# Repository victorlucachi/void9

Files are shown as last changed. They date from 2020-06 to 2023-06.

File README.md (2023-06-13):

# VOID9
*A 3x3 handwired macropad*

VOID9

The VOID9 is a 3d printed, handwired, 4x4 macropad running QMK Firmware on a Pro Micro controller.

I suggest printing the case using a 0.4 mm nozzle, supports are not needed for any of the parts.

You might want/need to use small dabs of hot glue to secure the switches in the plate depending on how well calibrated your printer is (if you're generous with it, it will add to the weight of the keyboard and it might change the feel of it).

Dont overtighten the screws as the threads might get stripped.

# WARNING

Comlumn pinout has been revised, if you have an older build of the macropad (built before October 2022, which was using pins D1, D0, D4) edit the info.json file in the firmware forks in order to reflect your wiring!

# Bill Of Materials

* 9 x diodes ([tme.eu](https://www.tme.eu/ro/en/details/1n4148-dio/tht-universal-diodes/diotec-semiconductor/1n4148/)/[aliexpress](https://www.aliexpress.com/item/32729204179.html))
* 9 x Cherry MX style mechanical switches
* 9 x keycaps of choice
* 1 x Pro Micro ([aliexpress](https://www.aliexpress.com/item/32902569443.html))
* 24 AWG (0.2 mm2) wire
* 4 x 8mm bumpons

### Redux
* 6 x M2x3x3.5 OD heat inserts ([aliexpress](https://www.aliexpress.com/item/4000585933306.html?spm=a2g0o.order_list.order_list_main.33.21ef1802vdSNrS))
* 4 x M2x10 Allen head screws ([aliexpress](https://www.aliexpress.com/item/32966941844.html?spm=a2g0o.order_detail.order_detail_item.9.722ff19cyjrixq))
* 2 x M2x6 Countersunk screws ([aliexpress](https://www.aliexpress.com/item/32968097507.html?spm=a2g0o.order_list.order_list_main.32.21ef1802vdSNrS))

### V1
* 4 x M3x10 Allen head bolts ([tme.eu](https://www.tme.eu/ro/en/details/m3x10_d912-a2/bolts/kraftberg/)/[aliexpress](https://www.aliexpress.com/item/32966941844.html))
* hotglue

# Community Mods

Contributions by @dlehman

Bottom - Angled - Short: Designed to be used with the middle ring (Middle - Angled: eg. if you want a contrasting color stripe). The short bottom + middle layer will be the same height as the regular bottom.

Bottom - Angled - Short - Teensy2: A version of the "Bottom - Angled - Short" model designed for a [Teensy 2.0 controller](https://www.pjrc.com/store/teensy.html) with a Mini (not "micro") USB port on it.

# Handwiring guide

I've also put together a pretty visual handwiring guide for the VOID9, that you can browse over [here](https://victorlucachi.ro/journal/void9-wiring-guide/).

|  	|  	|  	|
|---|---|---|

# Pin assignment

    ROW0    ROW1    ROW2
    F4      F5      F6

    COL0    COL1    COL2
    D1      D4      D0
    
    Encoder Pad A           Encoder Pad B
    B1                      F7
    B2                      B3

# QMK Vial Fork

A QMK Vial fork can be found [here](https://github.com/victorlucachi/vial-qmk/tree/dev_void/keyboards/handwired/void9).

Most features are disabled in order for the firmware to fit on the atmega32u4 present on the Pro Micro controllers, but if you want to tinker around with different features or if you're using a different MCU you can enable/disable them to suit your own needs by editing the rules.mk file in the vial keymap folder.

The web version of Vial is available at [vial.rocks](https://vial.rocks/); it runs in supported browsers (Chrome, Edge and Opera) without requiring an installation.

VOID9 Vial

# QMK Fork

A fork containing the QMK config files can be found [here](https://github.com/victorlucachi/qmk_firmware/tree/dev_void/keyboards/handwired/void9). Edit them to suit your own needs and build the firmware following the QMK docs.

If you plan on using the VIA configurator dont forget to download the json definitions file linked in this repository.



This work is licensed under a [Creative Commons Attribution-NonCommercial-ShareAlike 4.0 International License](https://creativecommons.org/licenses/by-nc-sa/4.0/).

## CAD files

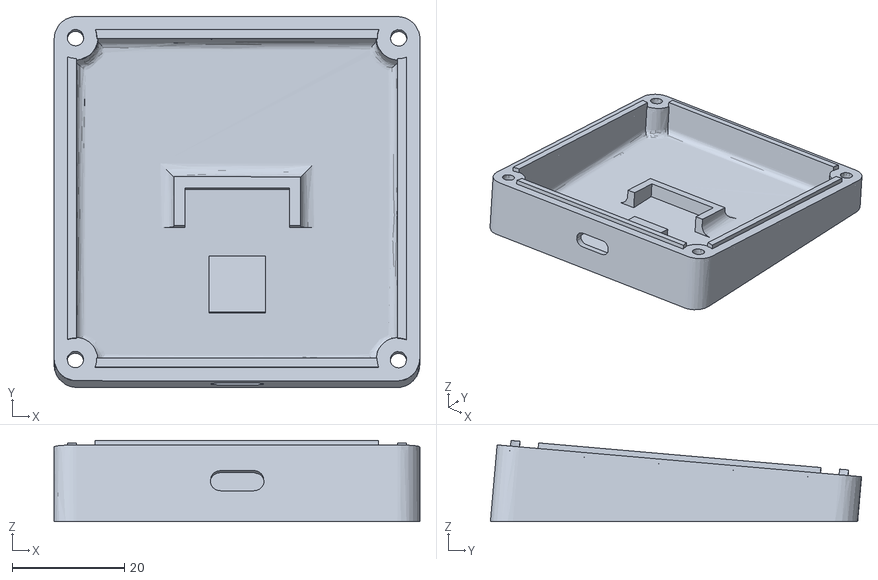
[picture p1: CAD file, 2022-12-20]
Community Mods/VOID9 - Bottom - Angled - Short.stl
65.2 x 66.1 x 14.4

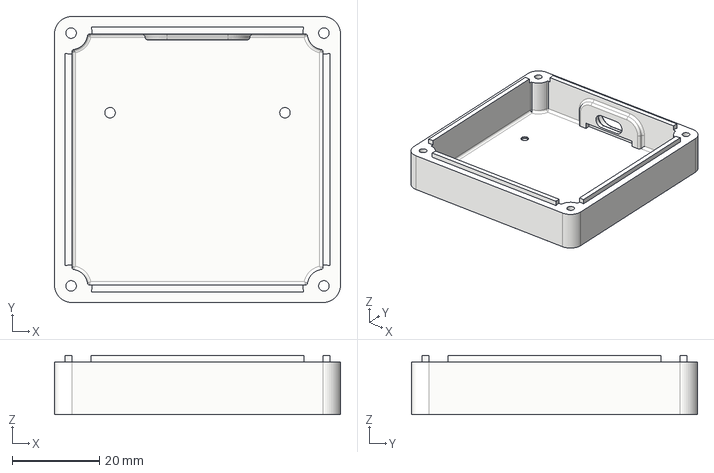
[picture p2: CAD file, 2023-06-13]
Redux/STEP/VOID9 Redux - Bottom - Flat.step
65.4 x 65.4 x 13.5 mm

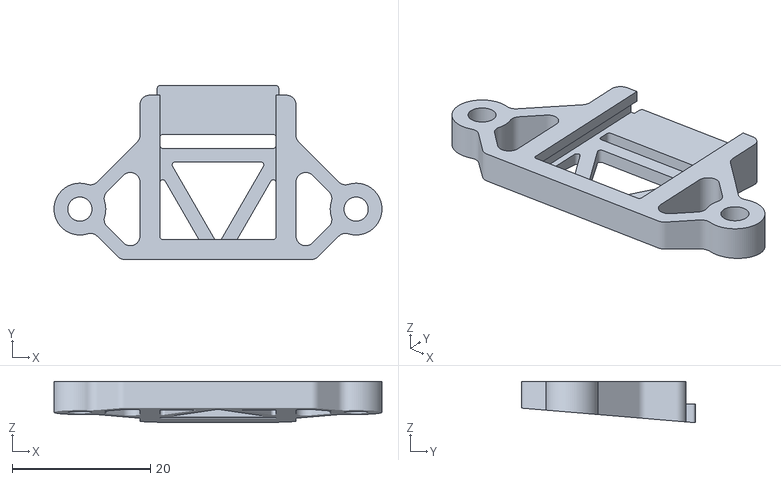
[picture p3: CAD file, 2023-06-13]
Redux/STL/Controller/21.5x18mm - Seeed Xiao - Angled.stl
47.5 x 25.2 x 6.00

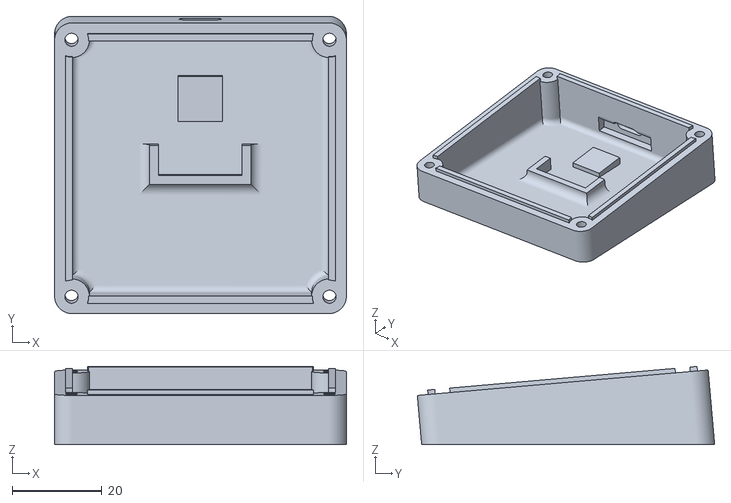
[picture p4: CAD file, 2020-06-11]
v1/STL/VOID9 - Bottom - Angled.stl
65.2 x 66.4 x 17.4

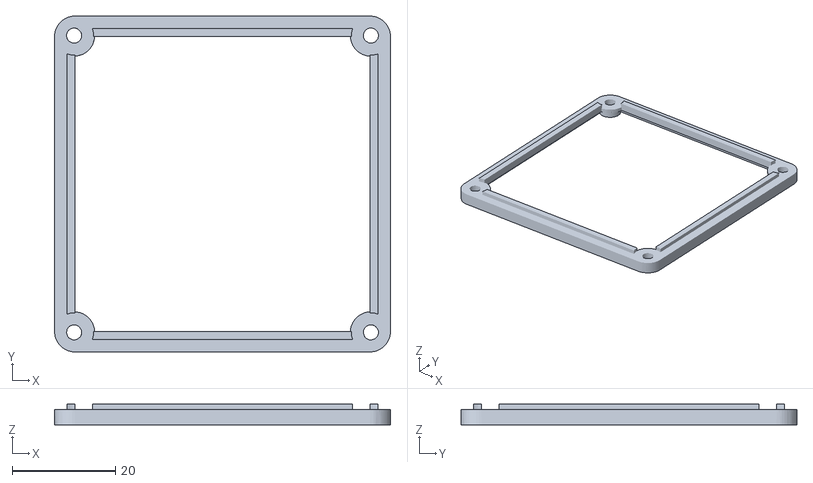
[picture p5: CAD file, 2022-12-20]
Community Mods/VOID9 - Middle - Angled.stl
65.2 x 65.2 x 4.00

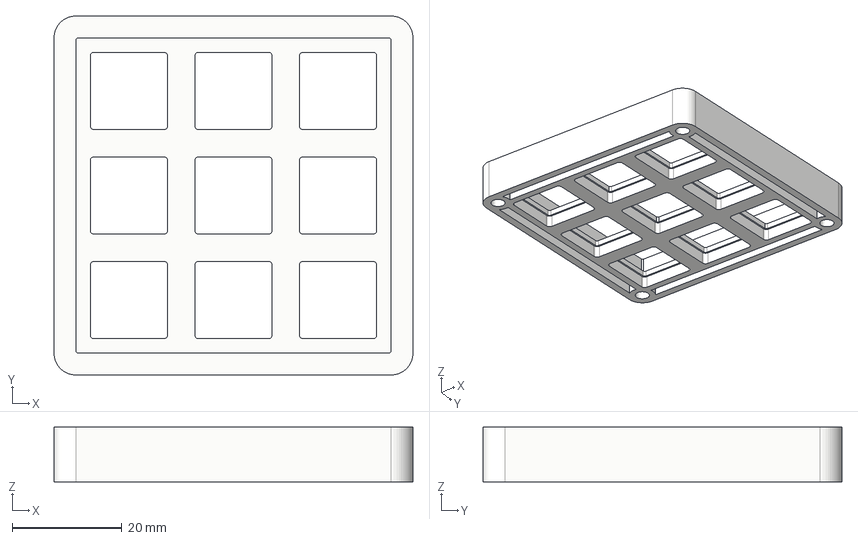
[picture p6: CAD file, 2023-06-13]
Redux/STEP/VOID9 Redux - Top - Flat.step
65.4 x 65.4 x 10.0 mm

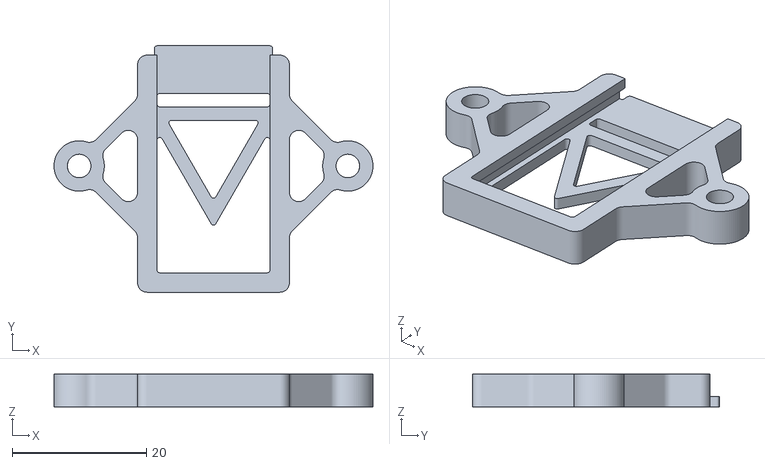
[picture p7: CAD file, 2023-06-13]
Redux/STL/Controller/33x18mm - Pro Micro - Flat.stl
47.5 x 36.7 x 4.86

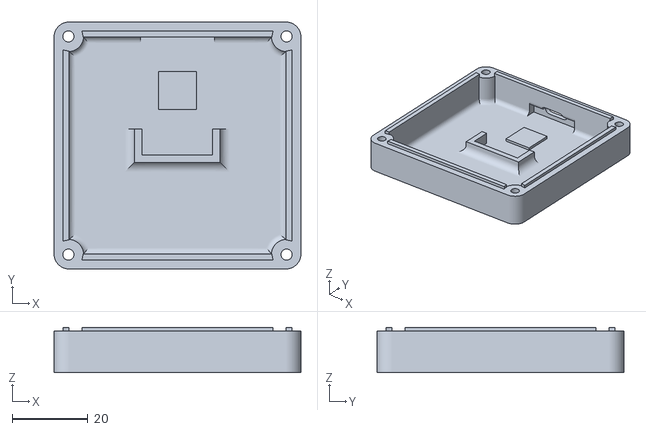
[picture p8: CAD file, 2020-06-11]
v1/STL/VOID9 - Bottom - Flat.stl
65.2 x 65.1 x 12.0

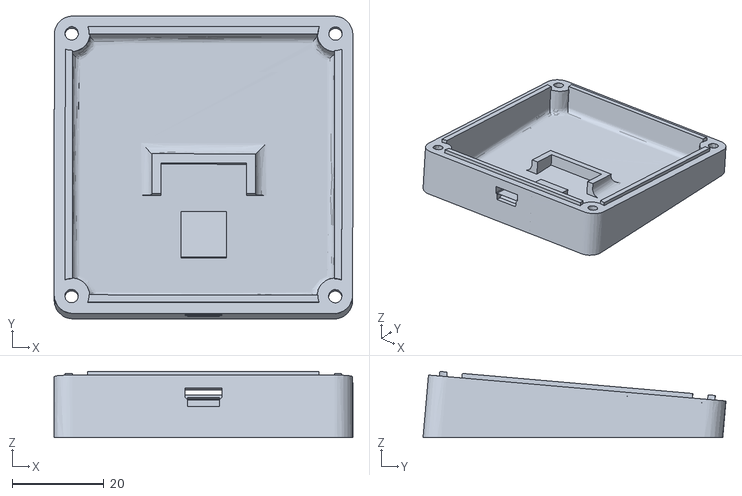
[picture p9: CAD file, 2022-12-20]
Community Mods/VOID9 - Bottom - Angled - Short - Teensy2.stl
65.2 x 66.1 x 14.4

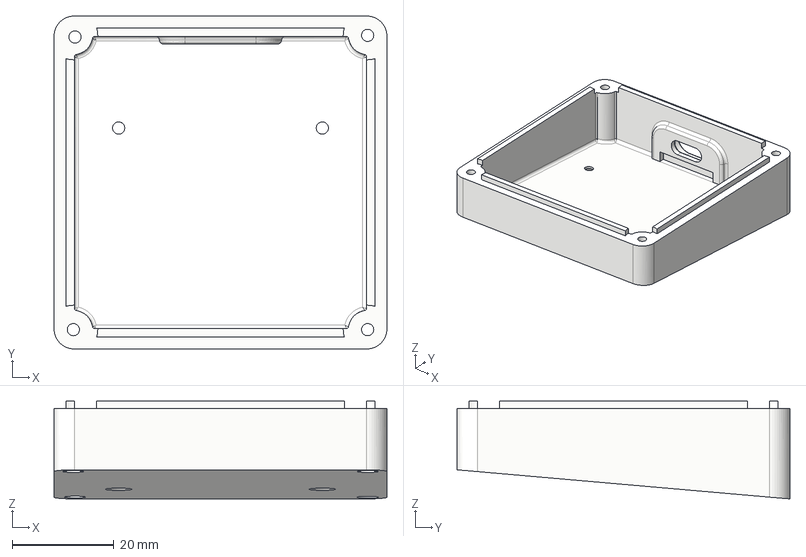
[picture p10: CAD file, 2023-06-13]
Redux/STEP/VOID9 Redux - Bottom - Angled.step
65.4 x 65.4 x 19.2 mm

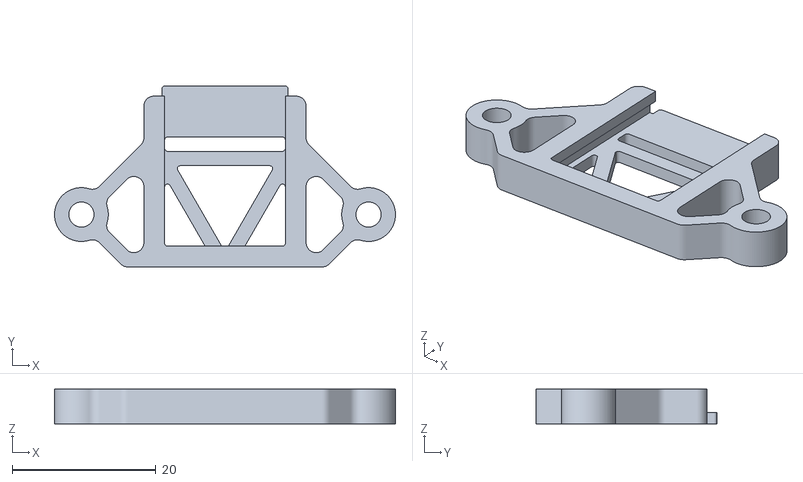
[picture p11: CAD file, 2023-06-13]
Redux/STL/Controller/21.5x18mm - Seeed Xiao - Flat.stl
47.5 x 25.2 x 4.86

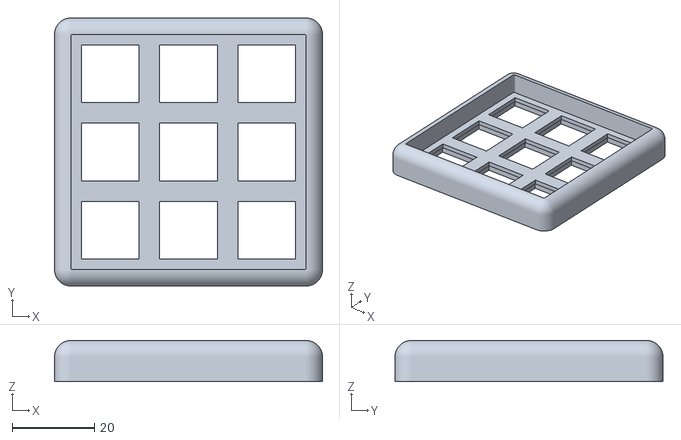
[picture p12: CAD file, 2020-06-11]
v1/STL/VOID9 - Top - Fillet.stl
65.2 x 65.1 x 10.0

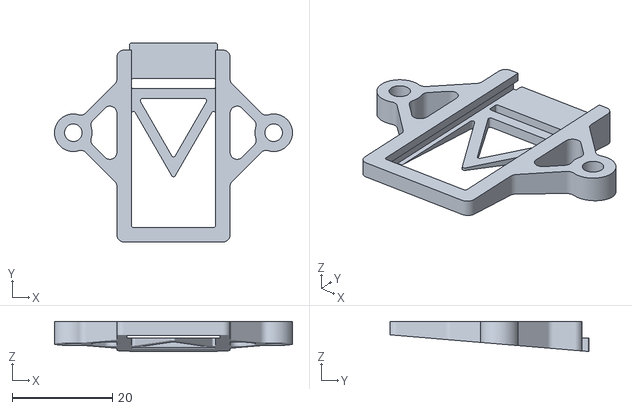
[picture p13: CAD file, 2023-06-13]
Redux/STL/Controller/36x18mm - Type C Pro Micro - Angled.stl
47.5 x 39.7 x 6.00

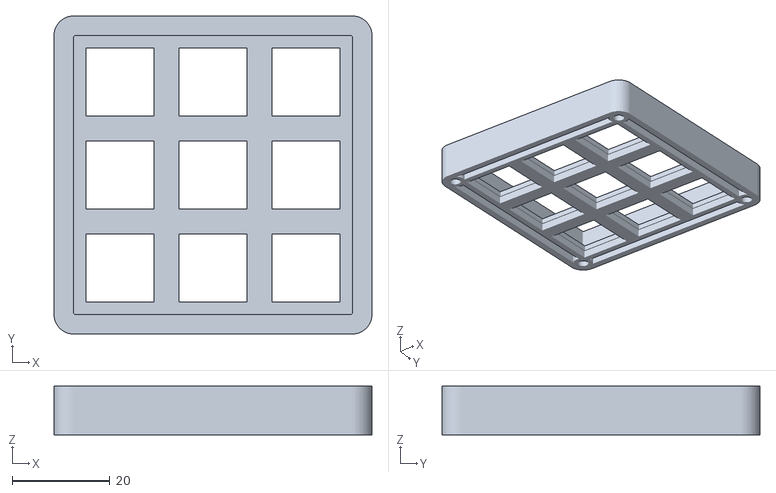
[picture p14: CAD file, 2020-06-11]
v1/STL/VOID9 - Top - Flat.stl
65.2 x 65.1 x 10.0

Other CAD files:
Redux/STL/Controller/36x18mm - Type C Pro Micro - Flat.stl
Redux/STL/Controller/33x18mm - Pro Micro - Angled.stl
Redux/STL/VOID9 Redux - Bottom - Angled.stl
Redux/STL/VOID9 Redux - Bottom - Flat.stl
Redux/STL/VOID9 Redux - Top - Flat.stl

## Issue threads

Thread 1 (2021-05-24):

Column pinout error and improvement

fleaz, 2021-05-24:
Hey Victor,

first of all big thanks for the Void9! Already build one myself and gathered the parts for two sets as presents for some friends of mine :)

But I found a small error in your handwiring guide on your website and related to this I would suggest an improvement:
On your website the pinout for the columns are swapped (It must be 1,0,4 not 0,1,4). In relation to this I would suggest to use the pin names which are printed on the board itself instead of using the 'internal names' which would make assembly way more user friendly in my opinion. Because while building the void9 I first had to google a pinout graphics of the Pro Micro which uses the internal name so I know which pads on the board to use.

With the printed names the mapping would become this:

|     | Row0 | Row1 | Row2 | Col0 | Col1 | Col2 |
|-----|------|------|------|------|------|------|
| Pin | A3   | A2   | A1   | 2    | 3    | 4    |

Best,
Felix

victorlucachi, 2021-07-31:
Hello Fleaz, my apologies for the very, very late reply.

Glad to hear that that you've built a bunch of them, thank you! I appreciate you bringing the column error to my attention, I will fix it as soon as I have the chance, hopefully by the end of next week.

I will also make use of your suggestion and at the very least I will include the alternate pin names, maybe even a pinout graph.

Cheers!

impoze, 2021-09-29:
first of all, thanks for providing the files & very clear guide.

I originally had some trouble with the board not working after flashing and wiring everything up and have spotted the issue.

In the wiring guide, the pin out is incorrect in step 8.

Column0 is marked as D0
Column1 is marked as D1

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

On the github it is documented correctly

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

shanselman, 2023-01-24:
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

Thanks! I got stuck here as well, thanks for this guide...this matches my printed pinouts. I didn't know the internal names.

Closed 2023-06-13.

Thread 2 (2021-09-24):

can't load json files

r4ph74, 2021-09-24:
hi .. I'm just new in QMK and Via ..

I tried to load your json file, but it comes up with error ..

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

May I know what is wrong ? do I have to plug the keyboard first before I can see the layout ?

Thanks in Advance

Regards,

Rafael

victorlucachi, 2021-09-26:
Hey Rafael!

Any additional info on the issue? The JSON seems to be loading just fine for me.

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

Closed 2023-06-13.

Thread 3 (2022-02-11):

Type-c compatible

Bischi1997, 2022-02-11:
Hi @victorlucachi

Can you maybe add the source files (eg. Fusion 360), so I could create an updated version for an Arduino micro with type-c (eg. Tenstar Robot pro micro)?
I'd be happy to add it via pull request, once done :)

Regards
Bischi

P.S. the angled file seems to be defective.

victorlucachi, 2022-02-11:
Hey,

Thanks for reaching out. I'll be releasing updated versions for my designs, which will include modular controller support among other things, in the near future; unfortunately they wont be open source.

Care to go into detail regarding the angled version, defective in what way? I can download and slice the file without any issues.

Bischi1997, 2022-02-11:
Cool to hear that an update is coming. Any rough estimate when the eta will be?

Just tried it again, seems to work now, no Idea what I did wrong last time :)

victorlucachi, 2022-02-11:
Hopefully in a week or two. I've been working on the files for a while now and they're mostly ready, I just have to re-print all of them to make sure that I didn't overlook anything.

Sweer, glad it worked.

Bischi1997, 2022-02-11:
Sure, let me know if I can test-print it for you as well.
Still waiting for my keyswitches, other than that I have all the components ready.

Bischi1997, 2022-04-02:
Hi Victor
Any Update?

victorlucachi, 2022-04-17:
Sorry for the late(ish) reply, I've been away for the past few weeks. Soon🤞

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

Sparticuz, 2023-05-25:
Any progress on this? I've got a waveshare rp2040 that I'd like to use in it

Bischi1997, 2023-06-13:
Seems like the answer is soon™

victorlucachi, 2023-06-13:
_soonish_.

I will update the repos either today or tomorrow, the files have been printed and tested before, but keep in mind that there might be issues.

I will have to rework the controller mount before posting the source files because in its current state, even though it's a parametric design, it sometimes breaks and the resulting models are unusable.

having said that, is this the controller that you plan on using @Sparticuz?

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

Sparticuz, 2023-06-13:
Yep, that's it. I've also got the qmk and via files to build the firmware for it and have been planning on posting them.

victorlucachi, 2023-06-13:
> Yep, that's it. I've also got the qmk and via files to build the firmware for it and have been planning on posting them.

Awesome. Reworked macropad files for the top/bottom are already up, I will add the controller mount shortly.

Closed 2023-06-13.

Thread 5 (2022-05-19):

Miss location pin out for colom 0 and colom 1

r4ph74, 2022-05-19:
hi victor ,

I just finally finish my macropad.. Thans for your tutorial .

but there is something miss in pinout  between col 0 and col 1.

I guess it should be

Col 0  D1
Col1  D0

btw do you have the tutorial  for replacing one button top left with the Rotary encoder ?

I have been thinking to create another one with Rotary encoder with  the same matrix .

regards,

Rafael

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

r4ph74, 2022-05-19:
the tutorial I follow is on your website .. https://victorlucachi.ro/journal/void9-wiring-guide/

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

-------------

I'm not sure I can follow, but I will make sure it when making another one with the encoder. I will ask you again .

Thanks alot Victor.

-------

r4ph74, 2022-05-19:
btw How to change the name of the USB instead of Void9 ?

Closed 2022-05-20.

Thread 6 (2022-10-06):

Void16 Compiling errors/issues [using a RP2040 as controller]

darknessblade, 2022-10-06:
Hello, I have some issues trying to compile the void16 using a RP2040 as controller

`
$ qmk compile -kb handwired/void16rp2040 -km default
Ψ Compiling keymap with make --jobs=1 handwired/void16rp2040:default

QMK Firmware 0.18.13
☒ handwired/void16rp2040: NO_ACTION_MACRO in config.h is no longer a valid option and should be removed
☒ handwired/void16rp2040: NO_ACTION_FUNCTION in config.h is no longer a valid option and should be removed
Making handwired/void16rp2040 with keymap default

☒ handwired/void16rp2040: NO_ACTION_MACRO in config.h is no longer a valid option and should be removed
☒ handwired/void16rp2040: NO_ACTION_FUNCTION in config.h is no longer a valid option and should be removed
Generating: .build/obj_handwired_void16rp2040/src/default_keyboard.c                                [WARNINGS]
 |
 | ☒ handwired/void16rp2040: NO_ACTION_MACRO in config.h is no longer a valid option and should be removed
 | ☒ handwired/void16rp2040: NO_ACTION_FUNCTION in config.h is no longer a valid option and should be removed
 |
arm-none-eabi-gcc.exe (GCC) 10.1.0
Copyright (C) 2020 Free Software Foundation, Inc.
This is free software; see the source for copying conditions.  There is NO
warranty; not even for MERCHANTABILITY or FITNESS FOR A PARTICULAR PURPOSE.

Generating: .build/obj_handwired_void16rp2040/src/info_config.h                                     [WARNINGS]
 |
 | ☒ handwired/void16rp2040: NO_ACTION_MACRO in config.h is no longer a valid option and should be removed
 | ☒ handwired/void16rp2040: NO_ACTION_FUNCTION in config.h is no longer a valid option and should be removed
 |
Generating: .build/obj_handwired_void16rp2040/src/default_keyboard.h                                [WARNINGS]
 |
 | ☒ handwired/void16rp2040: NO_ACTION_MACRO in config.h is no longer a valid option and should be removed
 | ☒ handwired/void16rp2040: NO_ACTION_FUNCTION in config.h is no longer a valid option and should be removed
 |
Generating: .build/obj_handwired_void16rp2040/src/layouts.h                                         [WARNINGS]
 |
 | ☒ handwired/void16rp2040: NO_ACTION_MACRO in config.h is no longer a valid option and should be removed
 | ☒ handwired/void16rp2040: NO_ACTION_FUNCTION in config.h is no longer a valid option and should be removed
 |
Compiling: .build/obj_handwired_void16rp2040/src/default_keyboard.c                                In file included from <command-line>:
./keyboards/handwired/void16rp2040/config.h:13:1: error: "/*" within comment [-Werror=comment]
   13 | /* Debounce reduces chatter (unintended double-presses) - set 0 if debouncing is not needed */
      |
./keyboards/handwired/void16rp2040/config.h:16:1: error: "/*" within comment [-Werror=comment]
   16 | /* disable these deprecated features by default */
      |
./keyboards/handwired/void16rp2040/config.h:17:1: error: unterminated comment
   17 | /*#ifndef LINK_TIME_OPTIMIZATION_ENABLE
      | ^
cc1.exe: all warnings being treated as errors
 [ERRORS]
 |
 |
 |
make[1]: *** [builddefs/common_rules.mk:359: .build/obj_handwired_void16rp2040_default/.build/obj_handwired_void16rp2040/src/default_keyboard.o] Error 1
Make finished with errors
make: *** [Makefile:414: handwired/void16rp2040:default] Error 1

`
Configuration:
[void16rp2040.zip](https://github.com/victorlucachi/void9/files/9722852/void16rp2040.zip)

darknessblade, 2022-10-06:
Removing every reference to the encoder from the settings seems to fix it, though I do not have the VIA Json file. And VIA does not automatically detect the keyboard/macropad

darknessblade, 2022-10-06:
With the Via definitions it seems to be working fine, I am able to remap it as well, without any issue.

If I encounter any new issues I will report back

darknessblade, 2022-10-12:
The only Issue I get is when I try to sideload the JSON file in VIAL

---------
Unsupported protocol version!
Please download latest Vial from https://get.vial.today/
------------
 File "main_window.py", line 284, in on_device_selected
  File "main_window.py", line 304, in rebuild
  File "editor\keymap_editor.py", line 125, in rebuild
  File "keycodes.py", line 870, in recreate_keyboard_keycodes

AttributeError: 'Keyboard' object has no attribute 'tap_dance_count'
-------------

Closed 2022-10-06.

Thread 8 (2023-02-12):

EC11 encoder pinout diagram

r4ph74, 2023-02-12:
HI Victor  It's me again .

I want to make a new one with encoder since I have successfully run the vial.  But I still confuse with the pinout.

the encoder have 5 pin  2 + 3 . I know the 2 pin one is for colom and other for the row, both pin act as  a button .  The other 3 pin is for rotary up and down.  the 2 pin is already known as you wrote, but how about the last pin ? where does it go ?  does it go to the same colom as the other 2 pin ? or goes to "gnd" pin ?

if you have the diagram that would be delightful.

Thanks in Advance

Rafael

victorlucachi, 2023-02-12:
hey Rafael,

I dont have any diagrams, but you got it right.

the side with two pins gets wired into the key matrix. on the other side, out of the three pins the upper and lower ones are connected according to the pinout in the readme (pin A to B2 and pin B to B3), while the third middle pin gets connected to ground on the mcu.

r4ph74, 2023-02-12:
Ahh.. Thanks Victor!..

r4ph74, 2023-02-17:
hi Victor  it's me again .

 I have soldered Pin B1 (15)  gnd (ground) and B2 (16) .. but seems the vial doesn't recognise it ...

the press button works good as usual .

did I miss something ?

r4ph74, 2023-02-17:
Thanks VIctor , it's working  now. I missed how to read the pinout  you mentioned  in readme.

victorlucachi, 2023-02-17:
> Thanks VIctor , it's working now. I missed how to read the pinout you mentioned in readme.

no worries, glad it's working!

the pinout table is a bit confusing, I'll try to make things a little clearer in the future, and add mcu/encoder diagrams and highlight the used pins.

r4ph74, 2023-02-17:
That would be great. Thanks Victor.

Closed 2023-06-13.

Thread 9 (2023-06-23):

Waveshare rp2040 controller doesn't fit

Sparticuz, 2023-06-23:
The chips on the bottom of the waveshare rp2040 won't allow it to slide into the controller slides. Seems like a 1 or 2 mm spacer needs to be cut out of the middle

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

victorlucachi, 2023-06-23:
this thing will have close to no structural integrity at all 😅. please let me know if it works.

[waveshare-rp2040.zip](https://github.com/victorlucachi/void9/files/11849325/waveshare-rp2040.zip)

Sparticuz, 2023-06-23:
Lol, will do. It looks like about half that could probably be put back. Though, also once it's screwed in, that will add back a ton of rigidity. I really wish i had my calipurs here at work. :/

Sparticuz, 2023-06-28:
It worked much better, the only improvement would be to make the screw holes smaller because the m2 insert i was using was quite a bit smaller than the opening. I had to wiggle the insert around inside the hole to get it to melt the sides.

victorlucachi, 2023-06-28:
sweet. the inserts that I'm using (also linked in the bom) have an outer diameter of 3.5mm; they should fit the part.

Sparticuz, 2023-06-28:
I used the same inserts on the top part and they fit perfect, but on the controller mount the hole was much larger. Everything is working well though! thank you for altering the stl!

Closed 2023-06-28.

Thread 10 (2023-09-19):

Encoder Wiring

cgdsyldrm, 2023-09-19:
Hello, first and foremost thank you for this great project. It clearly help a person who is novice. So It helps me a lot without PCB hassle. I couldn't see any wiring process for EC11 Rotary Encoder? Do I need to connect diode for it along within the grid as well or can I directly solder the ends into pro micro?

Kinda regards.

cgdsyldrm, 2023-09-24:
I figured this out by looking at EC11 pinouts. I just wired thouse 2 ends as what a switch has. GND has a diode with it own row, switch belongs to a column and done.

I'm closing the issue.

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

Closed 2023-09-24.

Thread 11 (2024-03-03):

Contact

Mboehmlaender, 2024-03-03:
Hi there,

unfortunately, i could Not contact you via Email, so i just opened an issue. You can delete it afterwards, if you wish.

Some time ago, i stumbled upon your VOID9 macropad and i fell in love with it. I love the tiny, classy and simple design so i made a first print and wired it and it worked like a charme.

Then i decided to take it a step further and designed the VOID9.1. I forked your repo and modified the prints and added RGB-Support and rewrote some parts of the code. Now it's all done and i completed the readme on github and published the repo. I wanted to ask, if you could have a look at at https://github.com/Mboehmlaender/kb-void9.1 and tell me, if there are any licence issues in the code or the repo itself, so i can adjust it to give you the credit, you deserve. And maybe a star would be nice.

Thanks in advance und greetings from bavaria.

Michael

victorlucachi, 2024-03-03:
Hey Michael, and thank you for the kind words.

Everything seems in order, apart from that one small typo (my last name, in the [_About the Project_](https://github.com/Mboehmlaender/kb-void9.1?tab=readme-ov-file#about-the-project) section of the readme), and the license (my models are released under the [CC BY-NC-SA](https://creativecommons.org/licenses/by-nc-sa/4.0/) license. you should go over it, but to keep it short you would have to release your mods under the same license).

Cool stuff, nicely documented, and I appreciate you contacting me. Thanks again!

Mboehmlaender, 2024-03-04:
Hi Victor,

thanks for starring my fork, i really appreciate it. I made the modifications you stated and i hope that GH updates the license in the frontend soon.

I chose GPL license because there were GPL notes in the firmware (config.h) in your VIAL fork. Does this relate to the VIAL/QMK itself? Then i need to change it back as well.

Greetings

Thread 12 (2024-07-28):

Recommended print settings for redux controller

friction07, 2024-07-28:
What orientation are you supposed to print it ? What about supports?

victorlucachi, 2024-07-29:
up to you really, it's a ten minute print job. I usually print mine flat on the bed without any supports at all 🙃

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

Closed 2024-07-29.

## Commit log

2022-10-20 new pins & correct encoder definitions
2022-10-20 updated definitions to include rotary encoders
    multiple layout options that include one, two or no encoders.
2022-12-20 Added short bottom + middle layer models, and support for Teensy 2.0 controller.
    [VOID9 - Bottom - Angled - Short - Teensy2.stl, VOID9 - Bottom - Angled - Short.stl, VOID9 - Middle - Angled.stl]
2022-12-22 updated readme/community mods
    [VOID9 - Bottom - Angled - Short - Teensy2.stl, VOID9 - Bottom - Angled - Short.stl, VOID9 - Middle - Angled.stl]
2023-06-13 redux prep
    - restructured repo
    - added precompiled fw
    - prep for redux models
    [VOID9 - Bottom - Angled.stl, VOID9 - Bottom - Flat.stl, VOID9 - Top - Fillet.stl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]
2023-06-13 VOID9 Redux
    - added redux models
    - modular pro micro controller mount
    - m2 hardware
    - m2 brass inserts
    [VOID9 Redux - Bottom - Angled.step, VOID9 Redux - Bottom - Angled.stl, VOID9 Redux - Bottom - Flat.step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]
2023-06-13 properly export step files
    [VOID9 Redux - Bottom - Angled.step, VOID9 Redux - Bottom - Flat.step, VOID9 Redux - Pro Micro - Angled.step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]
2023-06-13 modular controller mounts
    - added modular mounts for a couple of controllers
    [21.5x18mm - Seeed Xiao - Angled.stl, 21.5x18mm - Seeed Xiao - Flat.stl, 23.5x18mm - Waveshare rp2040 zero - Angled.stl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]
2023-07-03 removed waveshare controller mount
    [23.5x18mm - Waveshare rp2040 zero - Angled.stl, 23.5x18mm - Waveshare rp2040 zero - Flat.stl]

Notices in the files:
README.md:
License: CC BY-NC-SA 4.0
